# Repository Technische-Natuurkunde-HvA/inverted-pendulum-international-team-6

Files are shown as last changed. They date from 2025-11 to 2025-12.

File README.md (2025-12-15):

# Inverted Pendulum Project - Team 6 #

This project was carried out by a colaboration of students from ISEL (Lisbon Higher Institute of Engineering) and the University of Aplied Ciences of Amesterdam and it focuses on building and controlling an inverted pendulum, this system requires continuous feedback to stay balanced. For that feedback it will be needed some sensors, such as the AS5600 magnetic angle sensor, and a DC motor, this motor will provide the torque needed to correct deviations from upright.

---

# 1. Folders #

To keep our work clear, accessible, and easy to navigate, we organized the GitHub repository into a set of different folders that have all of the information obtained throughout the weeks.

## 1.1 [Code Folder:](/code) ##

This folder is divided by the different types of codes created, such as:

- [Aditional Challenges:](/code/Additional_Challenges) This folder stores all of the codes created for the additional challenges that we selected and completed;
- [Progress Codes:](/code/Progress_Codes) This folder holds the codes and the different versions of them created throughout the weeks;
- [Python:](/code/Python) This last folder has the python codes to extract information from the serial monitor of the arduino and create a graph with that information.

## 1.2 [Data Folder:](/data) ##

The data folder stores all of the data colected from the different expirements done.

## 1.3 [FeedBack Folder:](/feedback) ##

It houses all of the feedback reports done by both institutions teachers.

## 1.3 [Progress Folder:](/progress) ##

Within this folder are all of the progress reports done by the students throughout the weeks.

## 1.4 [Visuals Folder:](/visuals) ##

This folder is divided in to two folders, one that contains the figures ([Figures Folder](/visuals/figures)) and another one with the videos taken of the pendulum ([Videos Folder](/visuals/videos)).

---
# 2. Code #

The codes that are in the [Codes Folder](/code) are very simple it only needs to be copy and pasted in Arduino or the Python, but the one in the Additional challenges it is a bit different it is called a state machine so there will be two files in one code. 

**How to use a state machine code:** This code is different first it needs to copy and pasted the first file in said folder and then in the arduino app the user will need to press the icon with the three points on the far right and choose "create new tab" to put the other file.

⚠️ **Important:** In this process use always the terminologies that are in the name of the files. For example, when the user creates the new tab for the code said before it will be needed that the name of the file ends in ".h".

---
# 3. Repository Structure #

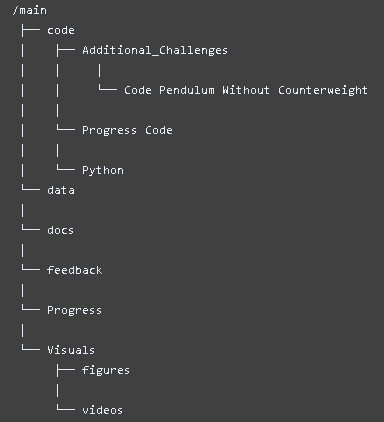
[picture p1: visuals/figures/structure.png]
Diagram


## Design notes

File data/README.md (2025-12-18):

The AS5600_Angle_vs_Time.png is a graph made to showcase the sensor working and giving a live output. The pendulum was moved by using the Pendulum_Flip_Timer code from the code/Progress_Codes map.

The Arduino_Connections_Pendulum.png file is used to showcase the connections from the Arduino to the pendulum and other devices.

The Stabilising_Pendulum_PID.gif is a short video to show how different PID values change the oscillation effect of the pendulum and how they help to stabilise it.

The data.txt file was is to show how the CSV file looks like.

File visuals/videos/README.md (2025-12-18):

These videos were taken to visualise our work and to show how progress has been made.

The bad wheel design videos are with the first wheel we had, which was not big enough to flip the pendulum.

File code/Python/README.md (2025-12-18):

This code is used to create graphs for the output of the Arduino.

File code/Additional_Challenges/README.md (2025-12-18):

In the Code_Data_Analysis map, there is a single code to read out the Arduino and sensors connected.

In the Code_Penduklum_Without_Counterweight map, there are two codes which need to be open in the Arduino simultaneously. This code is also used as the code with 2 PID controllers.

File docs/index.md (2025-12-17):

# 1. Project Motivation

The inverted pendulum project is interesting because it takes something that is naturally unstable and tries to balance it using intelligence and control. Imagine trying to keep a broomstick standing upright on your fingertip—it constantly wants to fall, so you must react quickly and precisely. Our project does the same thing, but with a small 3D-printed structure, sensors, electronics, and an Arduino program.

In simple terms, the system works by constantly measuring the pendulum’s angle and then using a motor to correct its movement. When the pendulum starts to fall to one side, the motor spins a 3D-printed wheel to generate the force needed to push it back toward the vertical position. This process repeats many times per second.

The control theory behind it is based on predicting how the pendulum will move and applying just the right amount of force at the right moment to keep it balanced. Instead of reacting randomly, the controller follows a mathematical strategy (implemented in code) that decides how strong and how fast the motor should respond.

Overall, the project is a practical demonstration of how engineers use mechanics, electronics, and smart algorithms to stabilize systems that would otherwise be impossible to balance on their own.

---
# 2. The Setup

# Mechanical Setup #

The mechanical structure is fully 3D-printed and designed to support an inverted pendulum stabilized by a reaction wheel. Its main components include:
 
- ## Pendulum Arm with Angle Encoder

The pendulum arm is a lightweight 3D-printed part mounted on a pivot.

Attached to this pivot is a dedicated angle encoder, which continuously measures the pendulum’s angular position. This sensor provides precise information about how far the pendulum is leaning and in which direction, which is essential for real-time control.

- ## Reaction Wheel

A large 3D-printed reaction wheel is mounted at the top of the system.

Metal bolts or weights are equally spaced around its outer rim to increase its moment of inertia, allowing it to generate stronger corrective torque when the motor accelerates or decelerates.

- ## Mounting Structure

All components are mounted on a rigid 3D-printed frame clamped to a table.

The goal is to minimize unwanted movement or vibrations while the wheel spins at high speed.

# Electronic Setup #

The electronic system provides sensing, computing, power control, and safety.

- ## Arduino (Main Controller)

An Arduino serves as the central processing unit.

It receives data from both encoders, runs the control algorithm, and commands the motor through the driver board.

- ## DC Motor (JGA25-370, 12 V)

The reaction wheel is directly driven by a JGA25-370 12 V DC motor.
This motor includes a built-in encoder, used to read the rotational speed and direction of the wheel. This information allows the control system to know exactly how much torque the wheel is producing at any moment.

- ## Encoders

There are two separate encoders, each with a specific function:

- ## Motor Encoder

Measures the reaction wheel’s rotation speed and direction. This allows precise control of the wheel’s acceleration, which is what generates the stabilizing torque.

- ## Pendulum Arm Encoder

Measures the real-time angle of the pendulum arm. This is the primary feedback signal used to determine whether the pendulum is falling and how the system should react.

- ## L298N Motor Driver

The motor is powered and controlled via an L298N dual H-bridge driver.

This module allows the Arduino to:

· Control the motor’s direction

· Adjust the motor’s speed using PWM

· Provide adequate current to the 12 V motor

- Power Electronics

A 12 V power supply feeds the motor driver and motor, while the Arduino is powered either through USB or a regulated 5 V source.

# Diagram of all the connections 



# Pendulum Assembly #



---
# 3. Implementation

## 3.1 Arduino Control Software (`code/Progress_Codes/`)

The Arduino control software is located in the `code/` directory and is responsible for the real-time control of the inverted pendulum system. The main program is implemented in the file `main.ino`, while the controller parameters and system constants are defined in `config.h`.

A PID controller is implemented to stabilize the pendulum around its unstable equilibrium point. The proportional, integral, and derivative gains, as well as the reference setpoint, deadband, and actuator limits, are defined in the configuration file. This separation allows systematic tuning of the controller parameters and improves code readability.

To understand how the PID works use this ilustration:

<script type="module"
  src="https://unpkg.com/@google/model-viewer/dist/model-viewer.min.js">
</script>

<div style="max-width: 900px; margin: 1rem auto; padding: 0 1rem;">

  <!-- GIF -->
  <div style="margin-top: 1.5rem; text-align: center;">
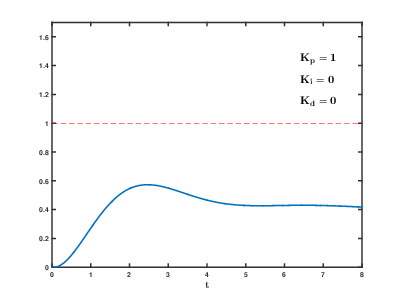
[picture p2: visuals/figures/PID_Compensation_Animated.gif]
PID Compensation Animation
    
  </div>

</div>

> ⚠️ **Important:**
> The ilustration above is a graphic that represents of how changing the PID values will chance the force exerted by the engine over time. 

At each control cycle, the Arduino reads the pendulum angle from the sensor and computes the control error with respect to the setpoint. The control law generates a control signal that is converted into a PWM output and applied to the motor through a motor driver. A minimum PWM threshold is used to compensate for motor dead zones and ensure reliable actuation.

For monitoring and experimental analysis, the measured pendulum angle is transmitted to a host computer via serial communication at a baud rate of 9600 bps. This data stream enables external observation of the system dynamics without affecting the real-time control loop.

## 3.2 Python Tools (`code/Python/`)

Python is used as a post-processing and visualization tool for the inverted pendulum experiments. The script `Code_to_create_Graphs.py`, located in the `code/` directory, establishes a serial connection with the Arduino using the `pyserial` library.

The script continuously receives the pendulum angle values sent by the Arduino and associates them with time stamps generated on the host computer. Basic data validation is performed to discard invalid serial data during acquisition.

After the acquisition is stopped by the user, the recorded data is plotted using the `Matplotlib` library. The resulting angle-versus-time plots provide a clear representation of the system response and allow qualitative evaluation of stability and control performance. These results support further physical interpretation and analysis of the inverted pendulum dynamics.

# 4. Experiments and results 

This section presents the experimental evaluation of the inverted pendulum system. Several tests were conducted to assess the controller’s ability to stabilize the pendulum under different conditions.

The folowing graph is a angle vs time experiment with pendulum stabilization to see how the AS5600 works:



The Results obtained after 4 weeks can be seen in the next videos:

<div style="position: relative; padding-bottom: 56.25%; height: 0;">
  <iframe
    src="https://www.youtube.com/embed/1MtrXlssoLU"
    style="position: absolute; top:0; left:0; width:100%; height:100%;"
    frameborder="0"
    allowfullscreen>
  </iframe>
</div>

<div style="position: relative; padding-bottom: 56.25%; height: 0; overflow: hidden;">
  <iframe
    src="https://www.youtube.com/embed/tHJFZTiYXPw"
    title="YouTube video player"
    frameborder="0"
    allow="accelerometer; autoplay; clipboard-write; encrypted-media; gyroscope; picture-in-picture"
    allowfullscreen
    style="position: absolute; top: 0; left: 0; width: 100%; height: 100%;">
  </iframe>
</div>

As it can be seen in the video after approximately 4 weeks the main objective of the project was sucessfully achived. Because of that the team discussed and decided that the from the additional challenges given the next target would be to make the pendulum stabelize without counterweight. After a week of progress the results achieved can be seen in the next video:

<div style="position: relative; padding-bottom: 56.25%; height: 0; overflow: hidden;">
  <iframe
    src="https://www.youtube.com/embed/hepXmcbHj-w"
    title="YouTube video player"
    frameborder="0"
    allowfullscreen
    style="position: absolute; top: 0; left: 0; width: 100%; height: 100%;">
  </iframe>
</div>

Some other challenges that were selected by the team were:
- Improvement of Design;
- Data Analysis;
- Creation of a Second PID (This challenge was applied in the no counterweight case and the achivement of completing that challenge was part from the creation of the second pid, for better stabilization).

The results of this three challenges can be seen in the next section.

# 5. Additional Challenges

For the improvement of the design it was created new parts that then were printed in a 3D Printer. This new parts give the pendulum more stabilization because of its design, and there are some extras, such as, to spaces to put the arduino and the L298N.

<script type="module"
  src="https://unpkg.com/@google/model-viewer/dist/model-viewer.min.js">
</script>

<div style="max-width: 900px; margin: 1rem auto; padding: 0 1rem;">
  <div style="position: relative; width: 100%; height: min(70vh, 650px); border-radius: 12px; overflow: hidden;">
    <model-viewer
      src="https://raw.githubusercontent.com/Technische-Natuurkunde-HvA/inverted-pendulum-international-team-6/main/visuals/files_newparts/Braco%20pendulo.STL"
      alt="Braço do pêndulo"
      camera-controls
      auto-rotate
      rotation-per-second="20deg"
      shadow-intensity="1"
      style="width: 100%; height: 100%; background: #f5f5f5;">
    </model-viewer>
  </div>
</div>

<script type="module"
  src="https://unpkg.com/@google/model-viewer/dist/model-viewer.min.js">
</script>

<div style="max-width: 900px; margin: 1rem auto; padding: 0 1rem;">
  <div style="position: relative; width: 100%; height: min(70vh, 650px); border-radius: 12px; overflow: hidden;">
    <model-viewer
      src="https://raw.githubusercontent.com/Technische-Natuurkunde-HvA/inverted-pendulum-international-team-6/main/visuals/files_newparts/base.STL"
      alt="Base (STL)"
      camera-controls
      auto-rotate
      rotation-per-second="20deg"
      shadow-intensity="1"
      style="width: 100%; height: 100%; background: #f5f5f5;">
    </model-viewer>
  </div>
</div>

The data Analysis challenge it was quite simple the team just created a new code that can be acessed by this link ([link](https://github.com/Technische-Natuurkunde-HvA/inverted-pendulum-international-team-6/tree/main/code/Additional_Challenges/Code%20Data%20Analysis))

The creation of a second PID was basically dividing the PID in two, in the left side of the up right position there is a PID and on the right it's the same. The team decided to do this because some time in some experiments it could be seen that the wheel going to one side had more force than going to the other side. The code for this challenge can be acessed by the link ([link](https://github.com/Technische-Natuurkunde-HvA/inverted-pendulum-international-team-6/tree/main/code/Additional_Challenges/Code%20Pendulum%20Without%20Counterweight))

# 6. Team and Credits

## The students:
- Duarte Anastácio
- Angelo Russo
- Nuno Mota
- Ricardo Alves
- Abdu Shehab

## Supervisors 
- Prof. Pedro Patrício
- Prof. Manfred Niehus
- Prof. Mark Bosman

## Collaborating Institutions





# 7. Repository

Project Repository:

- [GitHub: inverted-pendulum-international-team-6](https://github.com/Technische-Natuurkunde-HvA/inverted-pendulum-international-team-6)

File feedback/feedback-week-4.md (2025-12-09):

- Your weekly progress report gives a decent overview of your achievements this week. A more in-depth reflection would have been better though.
- Excellent you have included the Arduino sketch in your weekly progress report. However, please write all comments in English! As an international team, you should collaborate on the same code.
- You have implemented some correction for the motor’s dead zone, but this might not be the most adequate solution.
- Great you give a clear overview of your values for the PID parameters.
- Wonderful you have included two links to video’s.
- Please move the “ramp up increment” sketch to the correct folder or delete it. In general, you should reorganize your repository by removing clutter.
- When tuning the parameters make sure you have a systematic approach. Decide on which parameters to change, observe the results and based on the results, decide which parameter to change next and by how much.
- Make sure that you report on the process and intermediate results. Explain how you made decisions and why, instead of just mentioning the final numbers.

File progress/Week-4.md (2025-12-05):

# Week 4

## 1. Progress description
This week we managed to stabilise the pendulum using and when it is stable, the position of the arm is almost perfectly vertical. 
The pendulum will also restabilise itself after you give it a little push (see visuals/videos/Pendulum_stable_V1.mp4).

## 2. Code
The code had been changed so that it can stabilise the pendulum using the magnetic sensor to state the current position.
The 3 values for our parameters differ between the Dutch and Portugese group, since we have different wheels (at least for now).

Here are the parameters for the spare wheel used in Portugal (`visuals/videos/WhatsApp Video 2025-12-2 at 14.23.48.mp4`):
```
K_p = 30.0
K_i = 5.0
K_d = 1.5
```

And these are the parameters for our official wheel (`visuals/videos/Pendulum_stable_V1.mp4`):
```
K_p = 35.0
K_i = 1.0
K_d = 1.0
```

The code that we used to implement this PID values is:
```c

// for more information on the PID library: 
// http://brettbeauregard.com/blog/2011/04/improving-the-beginners-pid-introduction/

#include <Wire.h>
#include <PID_v1.h>
#include <AS5600.h>

AS5600  as5600;  //create sensor object

unsigned long currentMs;  
unsigned long lastMs;     
const unsigned int FREE_RUN_PERIOD_MS = 5; 
double sig_angle_deg;  

// Motor control pins
const int motorPin1 = 10; 
const int motorPin2 = 11; 
const int enablePin = 9;  

double setpoint = 225.5; 
double output = 0;

// PID parameters
double Kp = 31.0;
double Ki = 5.0;
double Kd = 1.0;
PID myPID(&sig_angle_deg, &output, &setpoint, Kp, Ki, Kd, DIRECT);

// zona morta de equilíbrio (graus)
const double ANGLE_DEADBAND = 0.01;

// limites de PWM para remover dead zone
const int PWM_MIN = 47;   // mínimo permitido para o motor se mover

void readAndPrintAngle();

void setup() {
  pinMode(motorPin1, OUTPUT);
  pinMode(motorPin2, OUTPUT);
  pinMode(enablePin, OUTPUT);

  Wire.begin();
  as5600.begin();
  lastMs = millis();
  Serial.begin(9600);
  delay(2000);

  myPID.SetMode(AUTOMATIC);
  myPID.SetSampleTime(FREE_RUN_PERIOD_MS);
  myPID.SetOutputLimits(-255, 255);
}

void loop() {

  currentMs = millis();
  if (currentMs - lastMs >= FREE_RUN_PERIOD_MS) {

    readAndPrintAngle();

    myPID.Compute(); 

    double error = setpoint - sig_angle_deg;

    // 1) SE ESTÁ EM EQUILÍBRIO → MOTOR PARADO
    if (fabs(error) <= ANGLE_DEADBAND) {
      analogWrite(enablePin, 0);
      digitalWrite(motorPin1, LOW);
      digitalWrite(motorPin2, LOW);

      Serial.print(sig_angle_deg);
      Serial.print(" ");
      Serial.println(0);
      return;
    }

    // 2) APLICAR DEAD ZONE NO PWM DO MOTOR
    // output > 0 → garantir mínimo +47
    if (output > 0 && output < PWM_MIN) {
      output = PWM_MIN;
    }
    // output < 0 → garantir mínimo -47
    else if (output < 0 && output > -PWM_MIN) {
      output = -PWM_MIN;
    }

    // 3) CONFIGURAR DIREÇÃO DO MOTOR
    if (output > 0) {
      digitalWrite(motorPin1, LOW);
      digitalWrite(motorPin2, HIGH);
    } 
    else {
      digitalWrite(motorPin1, HIGH);
      digitalWrite(motorPin2, LOW);
    }

    // 4) ESCRITA DO PWM (valor absoluto)
    analogWrite(enablePin, abs(output));

    // Debug
    Serial.print(sig_angle_deg);
    Serial.print(" ");
    Serial.println(output);
  }
}

void readAndPrintAngle() {
  lastMs = currentMs;
  sig_angle_deg = (float)as5600.readAngle() * 0.0879; 
}
```

## 3. Results
Our results will be shown in the videos below, furthermore we have not decided which additional challenge we are going to choose for next week.

Progress Portugal:

[Ver vídeo](../visuals/videos/Progress_Week4.mp4)

Progress Netherlands:

[Ver vídeo](../visuals/videos/Pendulum_stable_V1.mp4)

## 4. Reflection 
This week we achieved stabilising the pendulum and this went a lot faster than expected.

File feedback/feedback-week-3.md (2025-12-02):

- This week’s progress report is too brief. It also does not include any code snippets or graphs. Please add these directly into your weekly progress update, rather than just mentioning them.
- All output-response curves appear to be missing.
- Please move the “ramp up increment” sketch to the correct folder or delete it.
- The code folder has several versions of a similar code. It is good to see your progress, but please do not save these as separate sketches. GitHub will keep track of the history every time you commit a new version.
- Wonderful your new wheel has led to better results. Well done for continuing to improve your design. And good that you have added pictures to your repository.
- Great that you included a new video of the pendulum swinging from one side to the other. However, this particular method is not recommended; switching the spin direction so suddenly can damage the motor.

General recommendations to all teams:
- Place your weekly progress reports in reverse order, with the most recent week at the top.
- Do not be afraid of Markdown. If you wish, you could start by writing a basic text file in Word and later convert it to Markdown.
- Always add annotations or description to all graphs, pictures, videos, code and data you share in your weekly progress report. Do not assume these are self-explanatory; your readers rely on your explanations to understand their relevance and importance.
- The weekly progress reports form the foundation of your final written product. The more clear, detailed, and comprehensive your reports are, the better prepared you will be to complete your final product.

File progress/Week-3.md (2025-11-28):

# About this document

This is a team document where you record your weekly progress. It is written in Markdown, which allows you to format content in a simple and readable way. The document is rendered directly in GitHub without the need for a compiler (unlike LaTeX). The syntax is relatively easy. An overview of commonly used Markdown syntax can be found here:  
https://www.markdownguide.org/basic-syntax/

Below you find an example of the sections that must be included in each weekly progress report.

Use the **same document for all weeks**. For each week, use the **same headers and subheaders**.

Use the GitHub repository to store important project files (code, visuals including videos and figures, data, etc.). If necessary refer to those files in this document using a hyperlink. 

---

# Week 3

## 1. Progress description

This week we made a new wheel design (bigger), which is able to flip the pendelum over as you can see in the videos @/visuals.
both teams have now access to a functional code which can flip the penedelum at certain time intervals and is able to make an output response-cure and measure the rpm of the wheel.

## 2. Code

Both teams theire codes are in the code file inside the repository.

## 3. Results

Our pendelums can now flip over, without using maximum power. We also have the ability to ramp up or down our wheel speed.

## 4. Reflection 

We learned more about github, arduino and how you can bring the pendelum in motion.
Next week our focus will be on balancing the pendelum.

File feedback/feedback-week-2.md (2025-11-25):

- Your weekly progress report is very good. Great you included a picture of the pendulum, some code, and graphs. The text is clear.
- Wonderful you have included a python script which both saves and plots the data. Please also save this code in the ‘code folder’. In general, you should upload all your code to this folder on GitHub.
- Good you also uploaded some videos of the pendulum.
- Any code for the motor and encoder is lacking entirely. How do you intend to automize the measurements of motor RPM?

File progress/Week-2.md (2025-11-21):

# Week 2

## 1. Progress description
Pendulum is built and complete, sensor is working, but the pendulum does not swing around. 
This is because the engine doesn't have enough power to create enough momentum to flip over the pendulum itself.

Our sollution is to create a bigger wheel for the pendulum and we are getting a new engine for the pendulum which should produce more power.

## 2. Code

You can display code using three backticks (```) followed by an optional language extension.  
For example:  
- For C/C++ code, use `c` or `cpp`.  
- For Python, use `python`.

#### Example:
this is the code to getting the sensor to record the angle, to use this you must close the serial monitor before running or else it will give an access denied error.
```python
import serial
import time
import csv
import matplotlib.pyplot as plt

# ---------- SETTINGS ----------
PORT = "COM3"       # change to your Arduino port (COM4, COM5, ...)
BAUD = 11500         # MUST match Serial.begin() on Arduino
DURATION = 10       # seconds to record (2–10 sec is fine)
CSV_FILE = "as5600_data.csv"
PLOT_FILE = "as5600_plot.png"
# ------------------------------

def record_data():
    print(f"Opening {PORT} at {BAUD} baud...")
    ser = serial.Serial(PORT, BAUD, timeout=1)
    time.sleep(2)  # Arduino reset time

    start_time = time.time()
    print(f"Recording for {DURATION} seconds...")

    with open(CSV_FILE, "w", newline="") as f:
        writer = csv.writer(f)
        writer.writerow(["time_s", "angle_deg"])

        while time.time() - start_time < DURATION:
            line = ser.readline().decode("utf-8").strip()
            if not line:
                continue

            try:
                angle = float(line)   # one angle per line from Arduino
                t = time.time() - start_time
                writer.writerow([t, angle])
                print(t, angle)
            except ValueError:
                pass  # skip garbage lines

    ser.close()
    print("Done. Data saved to", CSV_FILE)

def plot_data():
    times = []
    angles = []

    with open(CSV_FILE, "r") as f:
        reader = csv.reader(f)
        next(reader)  # skip header
        for row in reader:
            times.append(float(row[0]))
            angles.append(float(row[1]))

    plt.figure(figsize=(8, 4))
    plt.plot(times, angles)
    plt.xlabel("Time (s)")
    plt.ylabel("Angle (deg)")
    plt.title("AS5600 angle vs time")
    plt.grid(True)
    plt.tight_layout()
    plt.savefig(PLOT_FILE)
    print("Plot saved as", PLOT_FILE)
    plt.show()

if __name__ == "__main__":
    record_data()
    plot_data()

``` 
## 3. Results





## 4. Reflection 

We learned how to use the pendulum and how to use the code to start the motor.

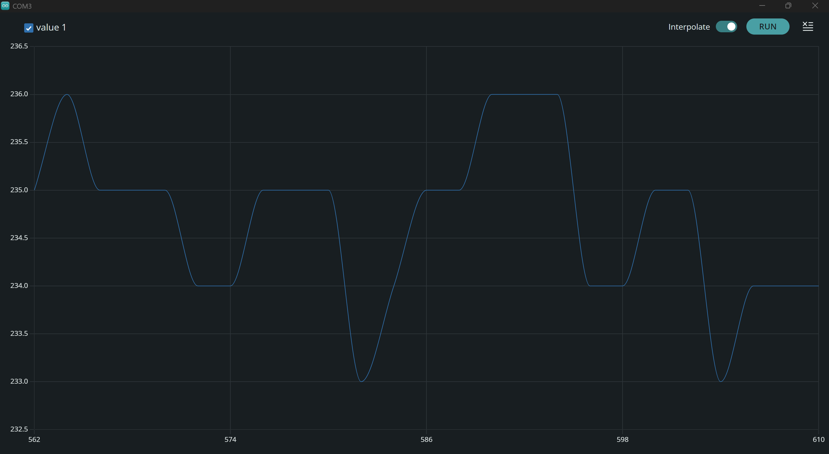
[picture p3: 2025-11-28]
visuals/figures/Screenshot 2025-11-28 160710.png

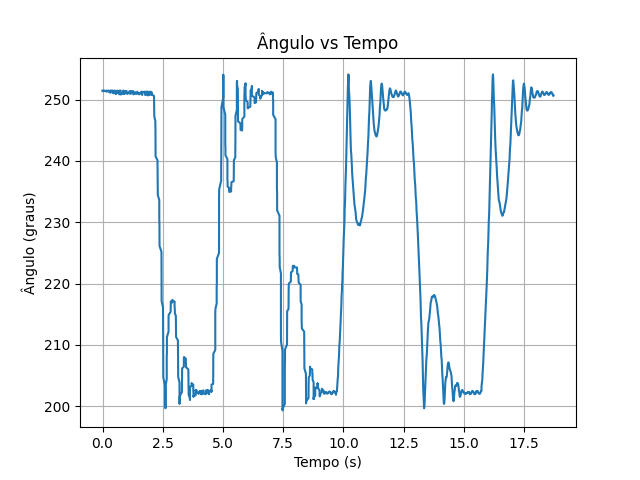
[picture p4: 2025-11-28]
visuals/figures/Graph Angle vs Time.png

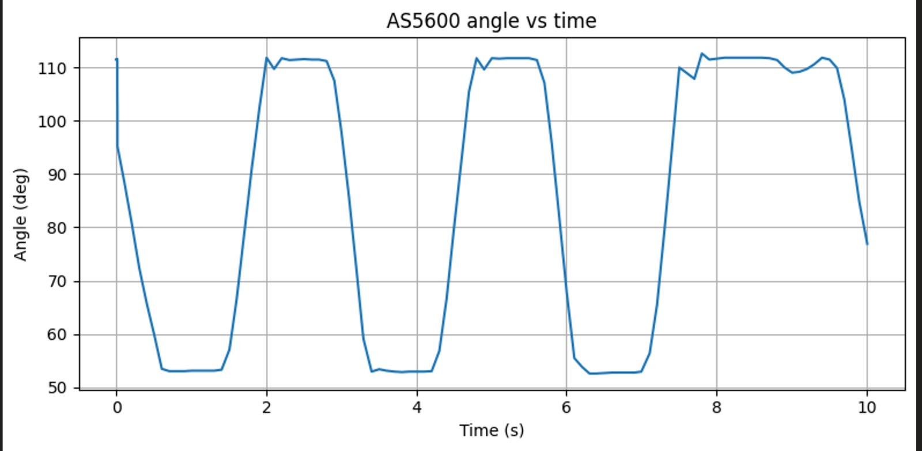
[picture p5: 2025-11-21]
visuals/figures/AS5600_Angle_vs_Time_V1.jpeg

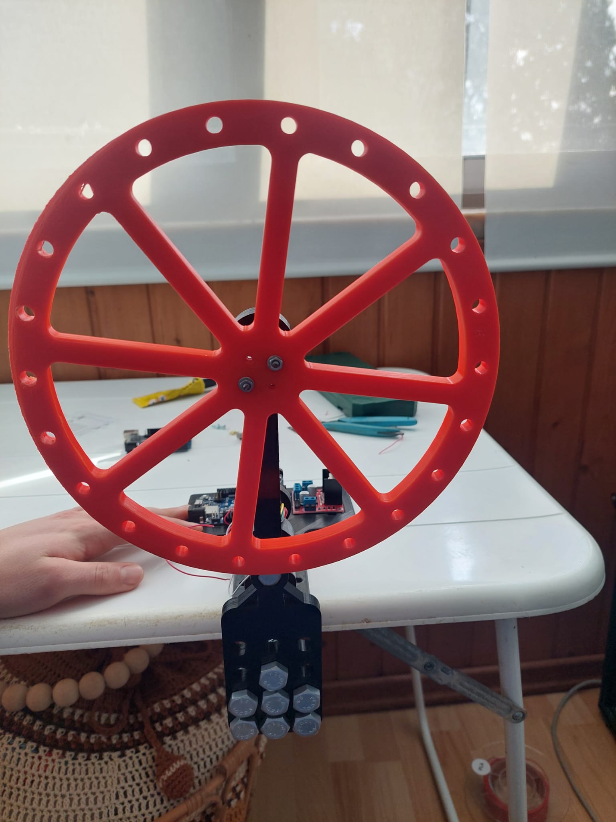
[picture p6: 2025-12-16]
visuals/figures/Final_Pendulum_Wheel_PT.jpeg

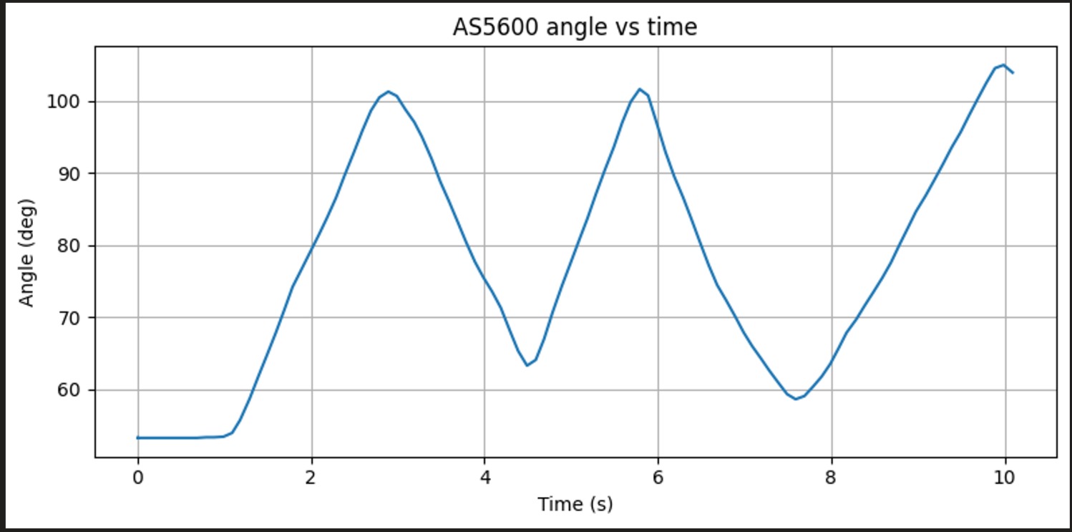
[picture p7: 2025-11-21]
visuals/figures/AS5600_Angle_vs_Time_V2.jpeg

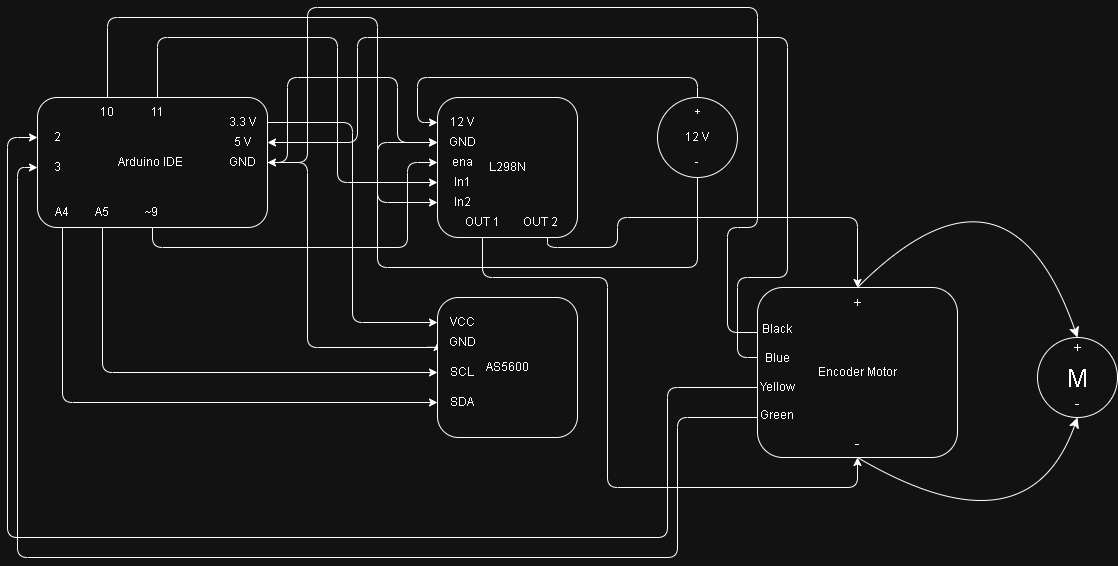
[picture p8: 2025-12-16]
visuals/figures/Diagram of electrical connections.png.png

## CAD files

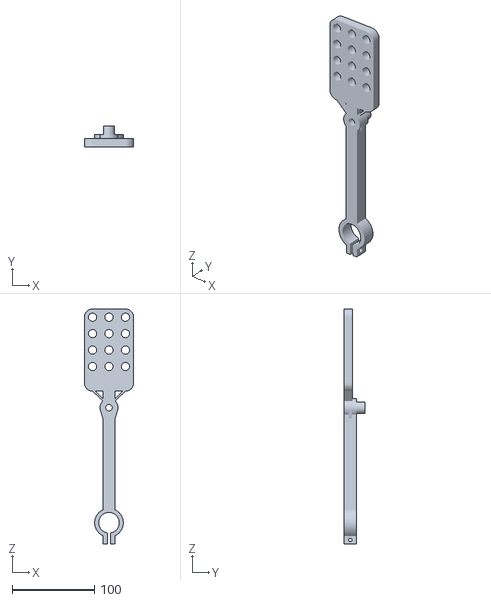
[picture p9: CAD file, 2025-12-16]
visuals/files_newparts/Braco pendulo.STL
60.0 x 25.0 x 285.9

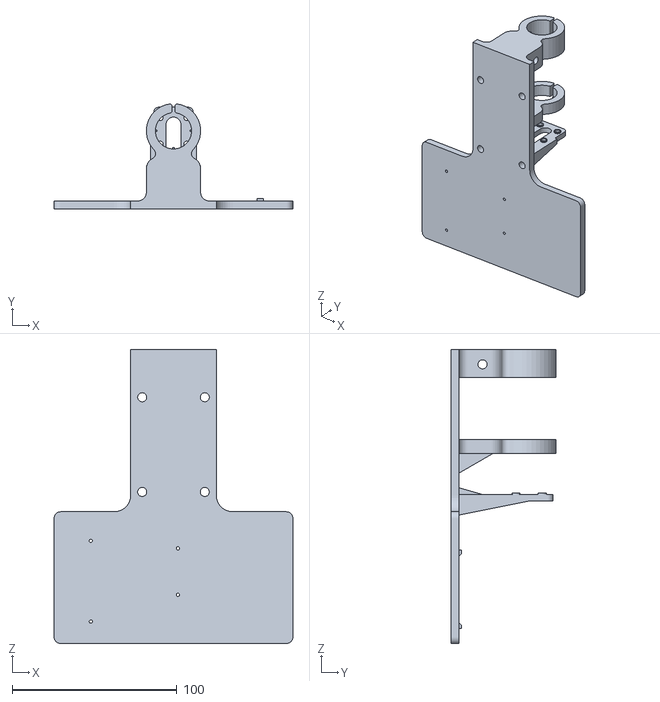
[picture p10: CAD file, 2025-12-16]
visuals/files_newparts/base.STL
145.0 x 63.9 x 178.5

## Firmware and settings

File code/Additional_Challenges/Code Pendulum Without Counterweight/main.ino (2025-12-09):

#include <Wire.h>
#include <PID_v1.h>
#include <AS5600.h>
#include "config.h"   // includes the parameters defined in the main config file

AS5600 as5600;

// ----------------------
// State machine
// ----------------------
enum State {
  STATE_CONFIG,
  STATE_RUN
};

State currentState = STATE_CONFIG;

// ----------------------
// Global variables
// ----------------------
unsigned long currentMs;
unsigned long lastMs;
const unsigned int FREE_RUN_PERIOD_MS = 5;
double sig_angle_deg;

// Motor
const int motorPin1 = 10;
const int motorPin2 = 11;
const int enablePin = 9;

// PID outputs
double outputRight, outputLeft;

// PID objects (gains come from config.h)
PID pidRight(&sig_angle_deg, &outputRight, &SETPOINT, KpR, KiR, KdR, DIRECT);
PID pidLeft (&sig_angle_deg, &outputLeft,  &SETPOINT, KpL, KiL, KdL, REVERSE);

// Startup impulse
bool startupImpulseDone = false;

// ----------------------
// Helper functions
// ----------------------
void readAngle() {
  lastMs = currentMs;
  sig_angle_deg = (float)as5600.readAngle() * 0.0879;
}

void driveMotor(bool right, int pwm) {
  if (right) {
    digitalWrite(motorPin1, LOW);
    digitalWrite(motorPin2, HIGH);
  } else {
    digitalWrite(motorPin1, HIGH);
    digitalWrite(motorPin2, LOW);
  }
  analogWrite(enablePin, pwm);
}

void startupImpulse() {
  if (!startupImpulseDone) {
    // right impulse
    driveMotor(true, STARTUP_PWM);
    delay(STARTUP_TIME_MS);
    // left impulse
    driveMotor(false, STARTUP_PWM);
    delay(STARTUP_TIME_MS);
    // stop
    analogWrite(enablePin, 0);
    digitalWrite(motorPin1, LOW);
    digitalWrite(motorPin2, LOW);
    startupImpulseDone = true;
  }
}

// ----------------------
// Setup
// ----------------------
void setup() {
  pinMode(motorPin1, OUTPUT);
  pinMode(motorPin2, OUTPUT);
  pinMode(enablePin, OUTPUT);

  Wire.begin();
  as5600.begin();
  Serial.begin(9600);
  delay(2000);

  lastMs = millis();
}

// ----------------------
// Main loop
// ----------------------
void loop() {
  switch (currentState) {

    case STATE_CONFIG:
      // PID configuration
      pidRight.SetMode(AUTOMATIC);
      pidRight.SetSampleTime(FREE_RUN_PERIOD_MS);
      pidRight.SetOutputLimits(0, 255);

      pidLeft.SetMode(AUTOMATIC);
      pidLeft.SetSampleTime(FREE_RUN_PERIOD_MS);
      pidLeft.SetOutputLimits(0, 255);

      currentState = STATE_RUN;
      break;

    case STATE_RUN:
      currentMs = millis();
      if (currentMs - lastMs >= FREE_RUN_PERIOD_MS) {
        readAngle();
        double error = SETPOINT - sig_angle_deg;

        if (!startupImpulseDone) startupImpulse();

        // Balance
        if (fabs(error) <= ANGLE_DEADBAND) {
          analogWrite(enablePin, 0);
          digitalWrite(motorPin1, LOW);
          digitalWrite(motorPin2, LOW);
          Serial.print(sig_angle_deg);
          Serial.print(" ");
          Serial.println(0);
          return;
        }

        // Choose PID
        if (error > 0) {
          pidRight.Compute();
          int pwm = (outputRight < PWM_MIN) ? PWM_MIN : outputRight;
          driveMotor(true, pwm);
          Serial.print(sig_angle_deg);
          Serial.print(" ");
          Serial.println(pwm);
        } else {
          pidLeft.Compute();
          int pwm = (outputLeft < PWM_MIN) ? PWM_MIN : outputLeft;
          driveMotor(false, pwm);
          Serial.print(sig_angle_deg);
          Serial.print(" ");
          Serial.println(-pwm);
        }
      }
      break;
  }
}

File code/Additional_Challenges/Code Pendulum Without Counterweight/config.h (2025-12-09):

#ifndef CONFIG_H
#define CONFIG_H

// ----------------------
// Tuning parameters
// ----------------------

// Setpoint
double SETPOINT = 225.5;

// Right side PID gains
const double KpR = 100.0;
const double KiR = 4.0;
const double KdR = 1.0;

// Left side PID gains
const double KpL = 100.0;
const double KiL = 4.0;
const double KdL = 1.0;

// Deadband (balance dead zone)
const double ANGLE_DEADBAND = 0.01;

// Minimum PWM
const int PWM_MIN = 47;

// Startup boost
const int STARTUP_PWM = 150;        // intensity
const int STARTUP_TIME_MS = 700;   // duration in ms

#endif

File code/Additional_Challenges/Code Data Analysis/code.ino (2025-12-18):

// This code is used to read out the Ardiono and sensors



#include <Wire.h>
#include <PID_v1.h>
#include <AS5600.h>

AS5600 as5600;

// -------------------------
// Timing
// -------------------------
unsigned long currentMs;
unsigned long lastMs;
const unsigned int FREE_RUN_PERIOD_MS = 5;


// Angle measurement
double sig_angle_deg;


// Motor control pins
const int motorPin1 = 10;
const int motorPin2 = 11;
const int enablePin = 9;


// PID PARAMETERS
double setpoint = 328;
double output = 0;

double Kp = 29.5;
double Ki = 5.0;
double Kd = 1;

PID myPID(&sig_angle_deg, &output, &setpoint, Kp, Ki, Kd, DIRECT);

// Balance deadband
const double ANGLE_DEADBAND = 0.01;

// PWM dead zone compensation
const int PWM_MIN = 47;

const byte ENCODER_PIN = 2;
const int PULSES_PER_REV = 330;

volatile long encoderPulses = 0;
unsigned long lastRpmMs = 0;
double motorRPM = 0;
int currentPWM = 0;

// Encoder ISR
void encoderISR() {
  encoderPulses++;
}

// Read angle from AS5600
void readAngle() {
  lastMs = currentMs;
  sig_angle_deg = (float)as5600.readAngle() * 0.0879;
}

// Setup
void setup() {
  pinMode(motorPin1, OUTPUT);
  pinMode(motorPin2, OUTPUT);
  pinMode(enablePin, OUTPUT);

  // Encoder setup
  pinMode(ENCODER_PIN, INPUT_PULLUP);
  attachInterrupt(digitalPinToInterrupt(ENCODER_PIN), encoderISR, RISING);
  lastRpmMs = millis();

  Wire.begin();
  as5600.begin();
  Serial.begin(9600);
  delay(2000);

  lastMs = millis();

  myPID.SetMode(AUTOMATIC);
  myPID.SetSampleTime(FREE_RUN_PERIOD_MS);
  myPID.SetOutputLimits(-255, 255);
}


// Main Loop
void loop() {

  currentMs = millis();

  if (currentMs - lastMs >= FREE_RUN_PERIOD_MS) {

    readAngle();
    myPID.Compute();

    double error = setpoint - sig_angle_deg;

    // 1: If angle is within deadband → stop motor
    if (fabs(error) <= ANGLE_DEADBAND) {
      analogWrite(enablePin, 0);
      digitalWrite(motorPin1, LOW);
      digitalWrite(motorPin2, LOW);

      currentPWM = 0;
      motorRPM = 0;

      Serial.print(sig_angle_deg);
      Serial.print(" ");
      Serial.print(motorRPM);
      Serial.print(" ");
      Serial.println(currentPWM);

      return;
    }

    // 2: PWM dead zone compensation
    if (output > 0 && output < PWM_MIN) output = PWM_MIN;
    else if (output < 0 && output > -PWM_MIN) output = -PWM_MIN;

    // 3: Motor direction
    if (output < 0) {
      digitalWrite(motorPin1, LOW);
      digitalWrite(motorPin2, HIGH);
    } 
    else {
      digitalWrite(motorPin1, HIGH);
      digitalWrite(motorPin2, LOW);
    }

    // 4: Apply PWM
    currentPWM = abs((int)output);
    analogWrite(enablePin, currentPWM);

    // 5: Calculate RPM every 100 ms
    const unsigned long RPM_INTERVAL_MS = 100;
    unsigned long now = currentMs;

    if (now - lastRpmMs >= RPM_INTERVAL_MS) {
      noInterrupts();
      long pulses = encoderPulses;
      encoderPulses = 0;
      interrupts();

      unsigned long dt = now - lastRpmMs;
      lastRpmMs = now;

      // RPM formula
      motorRPM = (pulses * 60000.0) / (PULSES_PER_REV * dt);
    }

    // 6: Serial output
    Serial.print(sig_angle_deg);
    Serial.print(" | ");
    Serial.print(motorRPM);
    Serial.print(" | ");
    Serial.println(currentPWM);
  }
}

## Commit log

2025-11-28 Update week 2 progress code
    current code for the swing of the pendelum
2025-11-28 Add files via upload
    The output response curve for the new wheel design and the new motor from both teams.
2025-12-02 Add PID control for motor based on angle measurement
2025-12-02 Refine PID settings and implement motor deadband
    Updated PID parameters and added deadband handling for motor control.
2025-12-05 Document PID control implementation and results
    Added implementation details for PID control including code example and results discussion.
2025-12-05 Update Week-4.md with PID implementation code
    Added code snippet for PID implementation details.
2025-12-05 Implement ramp up and down for motor output
    Added functionality to ramp motor output up and down step by step.
2025-12-09 Add main Arduino file for pendulum control
2025-12-09 Implement motor control with encoder feedback
    Added motor control and encoder functionality with output ramping.
2025-12-18 Update and rename data.txt to data.csv
    [data.csv]
